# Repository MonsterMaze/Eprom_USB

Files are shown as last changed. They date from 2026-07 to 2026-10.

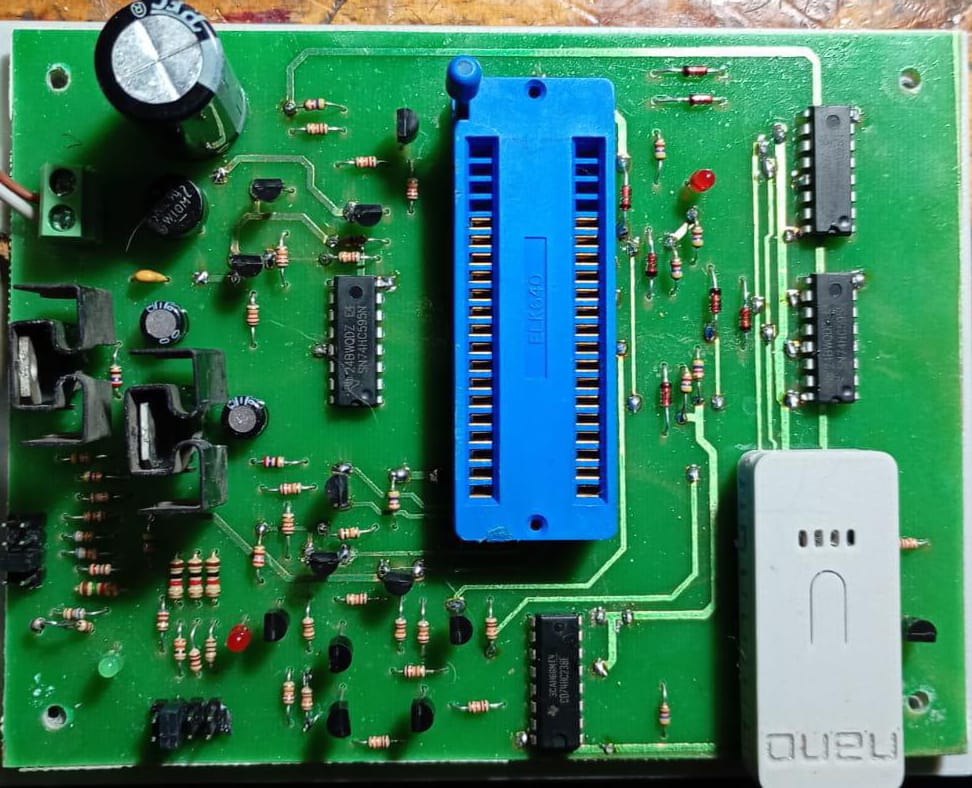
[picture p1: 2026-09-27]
images/new_pcb.jpg

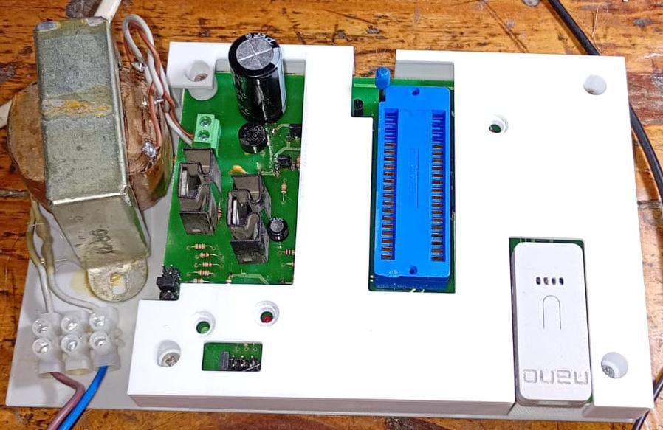
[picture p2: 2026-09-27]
images/new_pcb_3d_lid.jpg

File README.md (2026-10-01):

# Eprom_USB
2716 through 27080 Eprom Programmer
A programmer for UV EPROMs with capacities between 2Kb (2716 series) and 1Mb (27C080 series).  
It uses an Arduino NANO and few other components.  
As a starting point I used the excelent [EpromProgrammer_ciprian-stingu](https://github.com/ciprian-stingu/EpromProgrammer) project

## Why this project?
I need write eproms for pinball machines and I have two not working
- Parallel port (epromwillem) windows XP 32b
- Serial port (PGM27) for DOS.

So, I need a new Eprom programmer with a USB port.
That is why I started this project
my OS is Ubuntu 24.04 - 64b right now.

## Main features
* It supports a large number of EPROMs with different capacities  
* 2 programming speeds (normal & fast). Fast programming speed is available if you configure the VCC correctly  
* On fast programming alghoritm, writing a 27C040 EPROM takes around 290 seconds  
* Error detection on writing  
* Additional verify option  

## GUI Software (Ubuntu Linux_x64)
Actualized "CMakeLists.txt" and code with AI help for Ubuntu 24.04 OS.  
New version 1.12 with 0.35v of voltage margin. (0.25v)
The complete source for project is in [soft_linux](soft_linux)  
I have compiled for Ubuntu 24.04 and is included in Release v1.12 folder [Release 1.12/AppImage](https://github.com/MonsterMaze/Eprom_USB/releases/download/Linux/Eprom_USB-x86_64.AppImage)  
With some changes for icons, locale, debug etc.  
Last version Linux  [soft_linux v2.26](soft_linux)  

## GUI Software (windows_x64)
Actualized "CMakeLists.txt" for Windows 11 OS.  
QTCreator project compiler with some few changes.  
The complete source for project is in [soft_Win64](soft_Win64)  
I have compiled in w11 and is included in Release v1.12 folder [Release 1.12/Eprom_USB_v1.0_Windows_x64.zip](https://github.com/MonsterMaze/Eprom_USB/releases/download/v1.12/Eprom_USB_v1.0_Windows_x64.zip)

## GUI Software (windows_x64) v2
I have some problems with serial Port in windows (!)  
so...  
Modify all project and name v2
The complete source for project is in [soft_Win64_v2](soft_Win64_v2)  
I have compiled in w11 and is included in Release v1.20 folder [Release 1.20/Eprom_USB_v2_Windows_x64.zip](https://github.com/MonsterMaze/Eprom_USB/releases/download/v1.12/Eprom_USB_v1.0_Windows_x64.zip)  
I test the exe in w7-64b and w11-64b.

## Eprom_USB v1.0.0 - Multiplatform Release
This release contains the standalone, portable binaries for the Eprom USB Programmer software,   
fully compatible with both Windows and Linux. No external installation or build tools are required.

### 🪟 Windows Instructions (64-bit)
1. Download **`Eprom_USB_v1.0_Windows_x64.zip`**.  
2. Extract the `.zip` file entirely into a folder of your choice.  
3. Double-click **`Eprom_USB.exe`** to launch the graphical interface.  
*Note: All required Qt, Gettext (`libintl`), and `libiconv` DLLs are included inside the package.*

### 🐧 Linux / Ubuntu Instructions (64-bit AppImage)
1. Download **`Eprom_USB-x86_64.AppImage`**.  
2. Open your terminal, navigate to the folder where you downloaded the file, and grant it execution permissions:  
   ```bash
   chmod +x Eprom_USB-x86_64.AppImage
   ```
3. Launch the application by double-clicking it or running:
   ```bash
   ./Eprom_USB-x86_64.AppImage
   ```

⚠️ **Important for Linux Users (Serial Port Permission):**
If the application cannot open or detect your USB serial port, your Linux user might lack dialout permissions.  
Fix this by running the following command once, then log out and log back into Ubuntu:
```bash
sudo usermod -a -G dialout \$USER
```

---
*Developed with Qt 5 and CMake. Built with native MinGW (Windows) and GCC (Linux) compiler suites.*

## Arduino Software
The sketch for arduino nano is here: [arduino_nano](arduino_nano)

## Hardware
New schematics and PCB into FreeCAD project, was modify for me are in [FreeCAD](FreeCAD) folder.  
I add LM317 for the Vpp power (12.5v - 12.75 - 21v - 25v) from 24Vac input  
For non KiCad users, schematics and PCB [hardware](hardware) in PDF format  
New v2 PCB made by Ivana, in PDF format [hardware/PCB_v2](hardware/PCB_v2) front, bottom and silk

## Images
The screenshots and images of PCB and others are available in [images](images) folder

## Supported EPROMs

### 2716 — 2 KB

| Manufacturer | Part Number |
|---|---|
| Generic | 2716 |
| AMD | 2716 |
| Intel | 2716 |
| Hitachi | HN462716 |
| Mitsubishi | M5L2716K |
| Fujitsu | MBM2716 |
| Motorola | MCM2716 |
| NEC | µPD2716 |
| - | ET2716 |
| - | M2716 |

### 27C16 — 2 KB

| Manufacturer | Part Number |
|---|---|
| Generic | 27C16 |
| National Semi | 27C16 |
| AMD | AM2716B |
| National Semi | NMC27C16B |

### 2732 — 4 KB

| Manufacturer | Part Number |
|---|---|
| Generic | 2732 |
| AMD | AM2732 |
| AMD | AM9732 |
| Fairchild | F2732 |
| Hitachi | HN462732 |
| Intel | 2732A |
| ST | M2732A |
| Fujitsu | MBM2732 |
| NTE | NTE2732A |
| Toshiba | TMM2732D |
| NEC | µPD2732A |

### 27C32 — 4 KB

| Manufacturer | Part Number |
|---|---|
| Generic | 27C32 |
| AMD | AM2732B |
| National Semi | NMC27C32B |
| WSI | WS57C43C |

### 2764 — 8 KB

| Manufacturer | Part Number |
|---|---|
| Generic | 2764 |
| Intel | 2764A |
| ST | M2764A |
| Mitsubishi | M5L2764K |
| NTE | NTE2764 |
| Toshiba | TMM2764AD |

### 27C64 — 8 KB

| Manufacturer | Part Number |
|---|---|
| Generic | 27C64 |
| Microchip | 27C64 |
| Cypress | Cy7C266 |
| Fujitsu | MBM27C64 |
| National Semi | NMC27C64 |
| Texas Instruments| TMS27C64 |

### 27128 — 16 KB

| Manufacturer | Part Number |
|---|---|
| Generic | 27128 |
| Hitachi | HN4827128G |
| Hitachi | HN27128 |
| Intel | M27128A |
| ST | M27128A |
| Mitsubishi | M5L27128K |
| Mitsubishi | M5M27C128K |
| Fujitsu | MBM27128 |
| NTE | NTE21128 |
| Toshiba | TMM27128AD |
| Texas Instruments| TMS27128 |
| NEC | µPD27128 |

### 27C128 — 16 KB

| Manufacturer | Part Number |
|---|---|
| Generic | 27C128 |
| Microchip | 27C128 |
| AMD | AM27C128 |
| Atmel | AT27C128 |
| Cypress | CY27C128 |
| Sharp | LH57126 |
| ST | M27C128 |
| Oki | MSM27C128 |
| Fairchild | NM27C128 |
| National Semi | NM27C128 |
| - | QP27C128 |
| Texas Instruments| SMJ27C128 |
| Texas Instruments| TMS27C128 |

### 27256 — 32 KB

| Manufacturer | Part Number |
|---|---|
| Generic | 27256 |
| - | A68C256 |
| Atmel | AT27256 |
| Intel | 27256 |
| Mitsubishi | M5L27256K |
| Fujitsu | MBM27256 |
| Oki | MSM27256 |
| Toshiba | TMM27256 |
| NEC | µPD27256 |

### 27C256 — 32 KB

| Manufacturer | Part Number |
|---|---|
| Generic | 27C256 |
| Microchip | 27C256 |
| AMD | AM27C256 |
| AMD | AM27H256 |
| Sony | CXK27C256DQ |
| Cypress | CY27C256 |
| Cypress | CY27H256 |
| Cypress | CY7C274 |
| - | EM27C256 |
| - | FM27C256 |
| Hitachi | HN27C256A |
| Hitachi | HN27C256AG |
| ISSI | IS27C256 |
| ST | M27C256B |
| Mitsubishi | M5M27C256K |
| Fujitsu | MBM27C256 |
| - | 27HC256 |
| Oki | MSM27C256H |
| Fairchild | NM27C256 |
| National Semi | NM27C256 |
| National Semi | NM27LC256 |
| National Semi | NMC27C256 |
| National Semi | NMC87C257 |
| - | NPX27C256 |
| - | QP27C256 |
| SEEQ | 27C256 |
| SEEQ | M27C256 |
| ASI | SMJ27C256 |
| Texas Instruments| SMJ27C256 |
| - | SPM27C256 |
| Toshiba | TC57256 |
| Texas Instruments| TMS27C256 |
| Texas Instruments| TMS87C257 |
| NEC | µPD27C256 |

### 27512 — 64 KB

| Manufacturer | Part Number |
|---|---|
| Generic | 27512 |
| Intel | 27512 |
| AMD | AM27512 |
| Hitachi | HN27512 |
| ST | M27512 |
| Mitsubishi | M5L27512K |
| Oki | MSM27512 |
| Toshiba | TMM27512AD |

### 27C512 — 64 KB

| Manufacturer | Part Number |
|---|---|
| Generic | 27C512 |
| Microchip | 27C512 |
| Intel | 27C512 |
| Philips | 27C512 |
| AMD | AM27C512 |
| Sony | CXK27C512DQ |
| Cypress | CY27C512 |
| Cypress | CY27H512 |
| - | EM27C512 |
| - | FM27C512 |
| Hitachi | HN27C512 |
| ISSI | IS27HC512 |
| Fujitsu | MBM27C512 |
| Macronix | MX27C512 |
| National Semi | NM27C512 |
| National Semi | NM27P512 |
| ASI | SMJ27C512 |
| Texas Instruments| SMJ27C512 |
| Toshiba | TC57512AD |
| Texas Instruments| TMS27C512 |
| NEC | µPD27C512 |

### 27C010 — 128 KB

| Manufacturer | Part Number |
|---|---|
| Generic | 27C010 |
| AMD | AM27C010 |
| AMD | AM27H010 |
| AMD | AM27HB010 |
| Cypress | CY27C010 |
| Cypress | CY27H010 |
| Intel | 27C010 |
| - | EM27C010 |
| - | FM27C010 |
| Hitachi | HN27C101 |
| ISSI | IS27C010 |
| Mitsubishi | M5M27C101K |
| Fairchild | NM27C010 |
| National Semi | NM27C010 |
| National Semi | NMC27C010 |
| ASI | SMJ27C010 |
| Texas Instruments| SMJ27C010 |
| Texas Instruments| TMS27C010 |

### 27C1001 — 128 KB

| Manufacturer | Part Number |
|---|---|
| Generic | 27C1001 |
| Sony | CXK27C1001DQ |
| ST | M27C1001 |
| Fujitsu | MBM27C1001 |
| Oki | MSM27C1000 |
| Macronix | MX27C1000 |
| Toshiba | TC57C1001 |
| Toshiba | TC57H1001 |

### 27C020 — 256 KB

| Manufacturer | Part Number |
|---|---|
| Generic | 27C020 |
| AMD | AM27C020 |
| Cypress | CY27C020 |
| Intel | 27C020 |
| - | EM27C020 |
| ISSI | IS27C020 |
| National Semi | NM27C020 |
| Texas Instruments| TMS27C020 |

### 27C2001 — 256 KB

| Manufacturer | Part Number |
|---|---|
| Generic | 27C2001 |
| ST | M27C2001 |
| Oki | MSM27C2000 |
| NEC | µPD27C2001 |

### 27C040 — 512 KB

| Manufacturer | Part Number |
|---|---|
| Generic | 27C040 |
| AMD | AM27C040 |
| Cypress | CY27C040 |
| - | EM27C040 |
| - | FM27C040 |
| Intel | 27C040 |
| National Semi | NM27C040 |
| NXP | NXP27C040 |
| ASI | SMJ27C040 |
| Micross | SMJ27C040 |
| Texas Instruments| SMJ27C040 |
| Texas Instruments| TMS27C040 |

### 27C4001 — 512 KB

| Manufacturer | Part Number |
|---|---|
| Generic | 27C4001 |
| Hitachi | HN27C4001 |
| ST | M27C4001 |
| Fujitsu | MBM27C4001 |
| Oki | MSM27C401 |
| Macronix | MX27C4000 |
| Toshiba | TC57C4000 |
| NEC | µPD27C4001 |

### 27C080 — 1024 KB (1 MB)

| Manufacturer | Part Number |
|---|---|
| Generic | 27C080 |
| AMD | AM27C080 |
| Atmel | AT27LV080 |
| ST | M27C801 |
| Macronix | MX27C8000 |

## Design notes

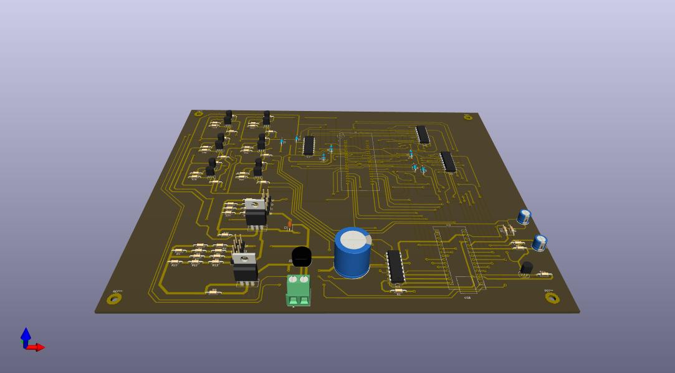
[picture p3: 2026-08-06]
images/Eprom_USB.jpg

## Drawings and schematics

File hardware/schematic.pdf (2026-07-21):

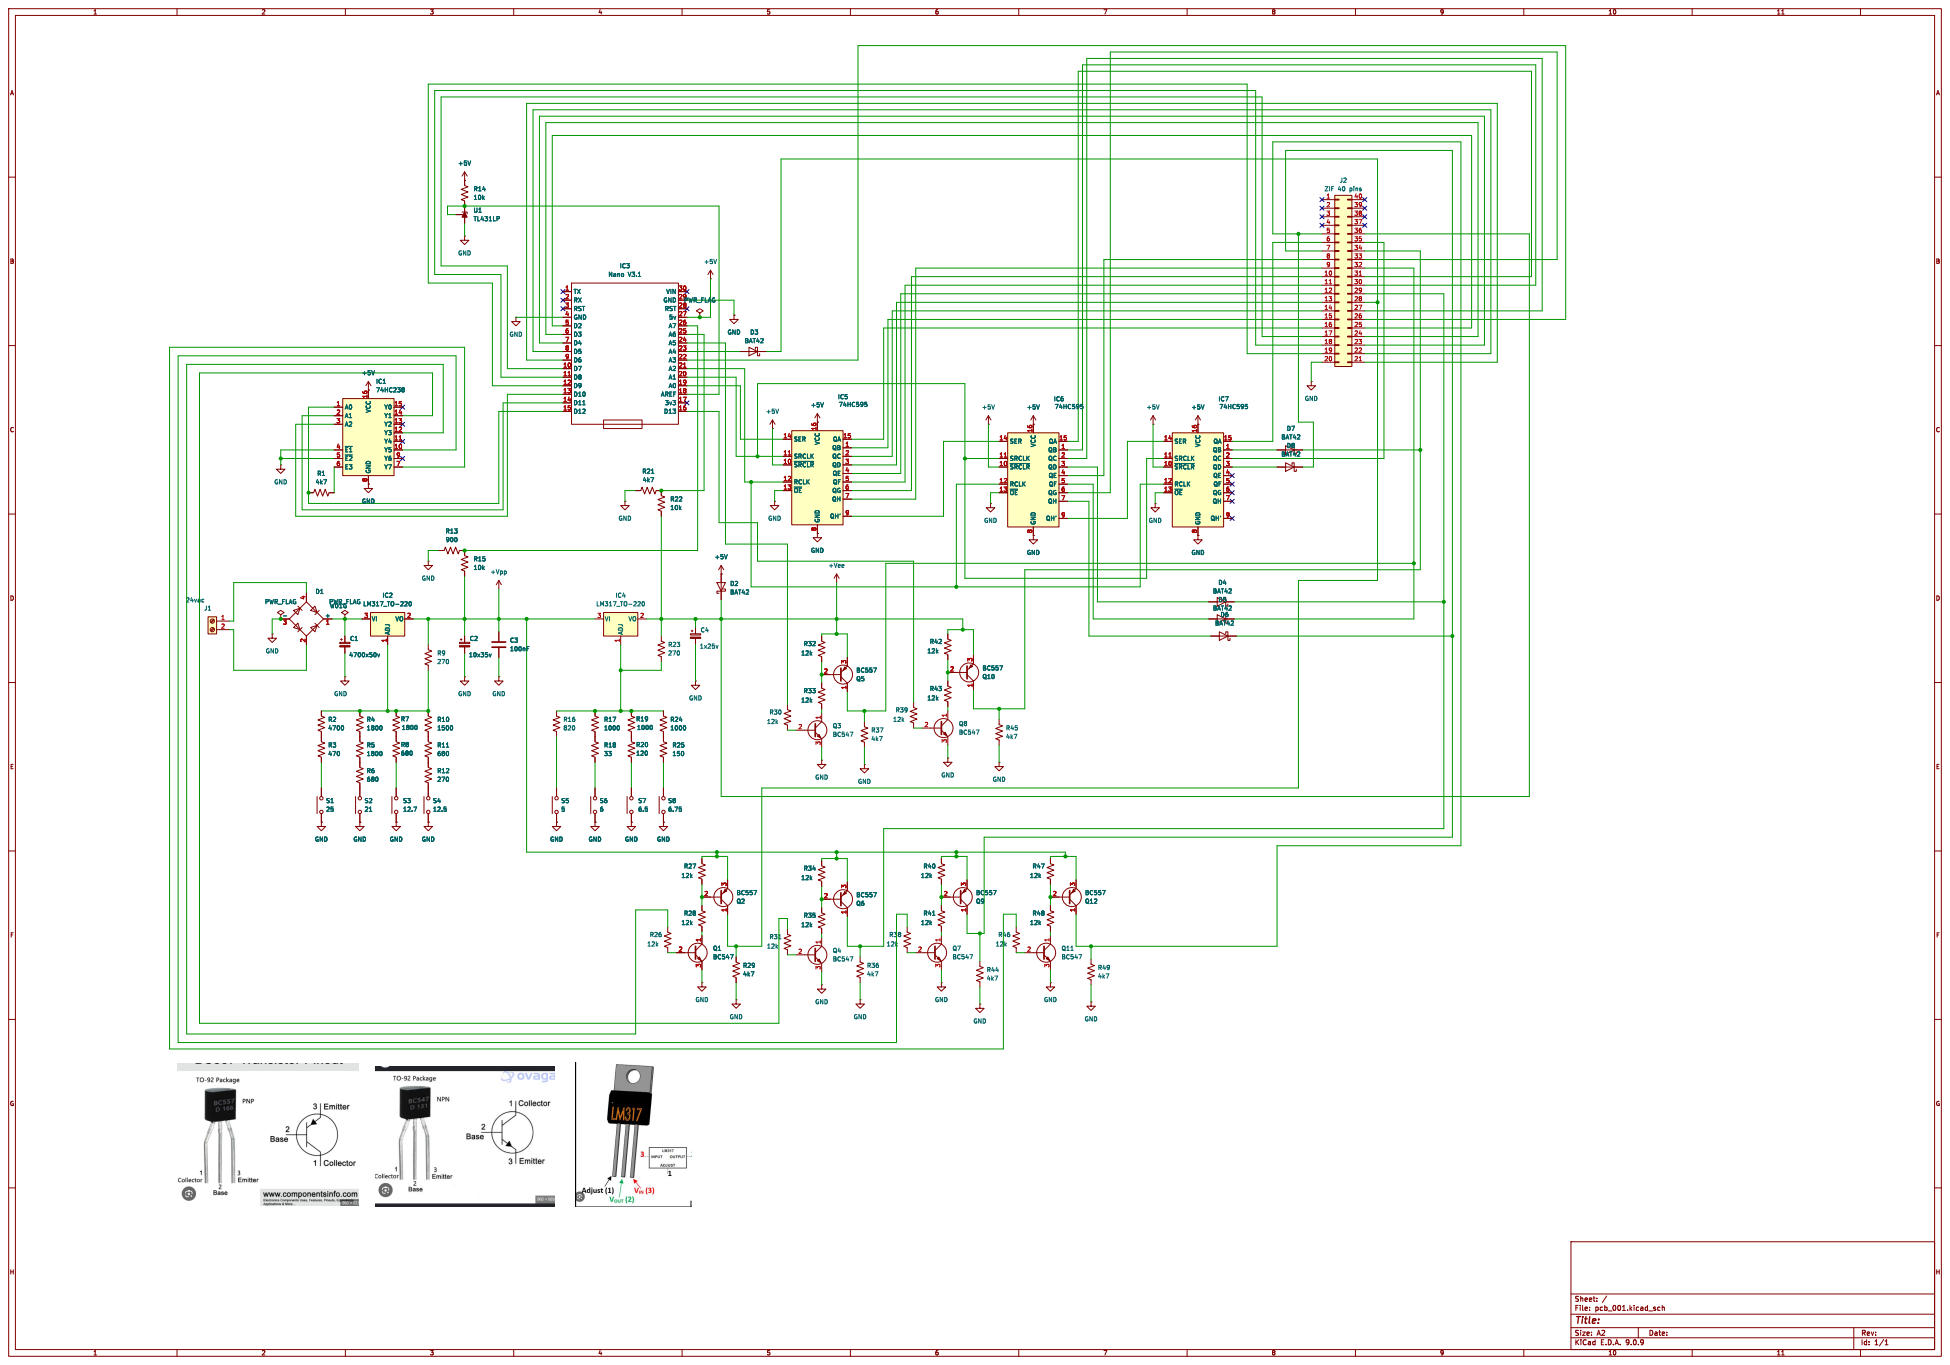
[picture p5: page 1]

8 QA 15 QB 1 QC 2 QD 3 QE 4 QF 5 QG 6 QH 7 QH' 9 +5V D8 BAT42 D7 BAT42 +5V

8 QA 15 QB 1 QC 2 QD 3 QE 4 QF 5 QG 6 QH 7 QH' 9 GND

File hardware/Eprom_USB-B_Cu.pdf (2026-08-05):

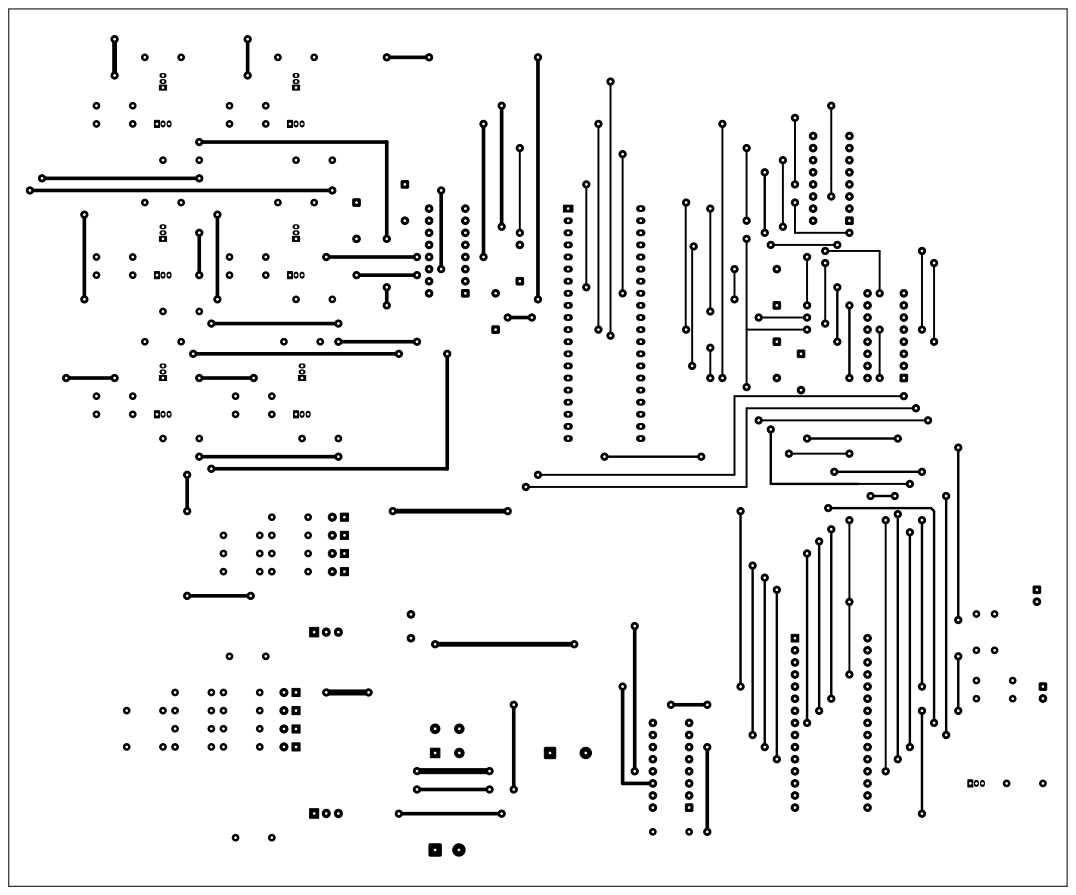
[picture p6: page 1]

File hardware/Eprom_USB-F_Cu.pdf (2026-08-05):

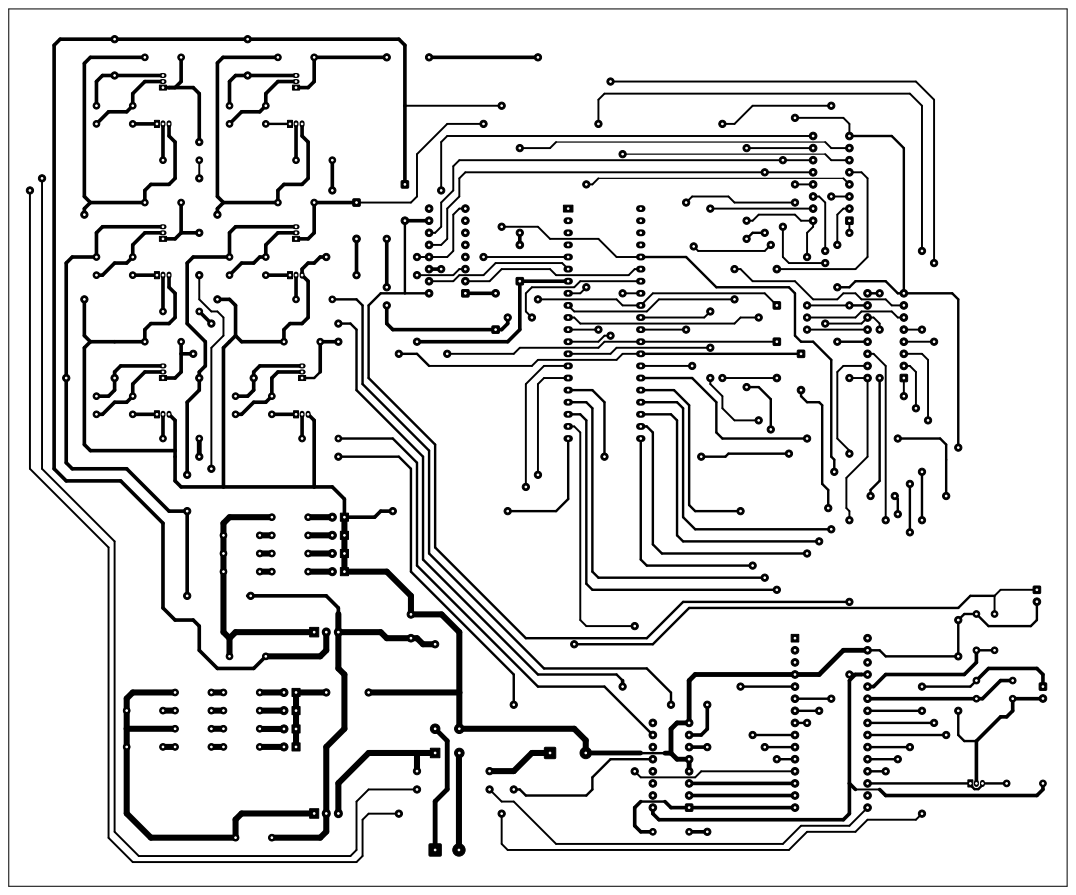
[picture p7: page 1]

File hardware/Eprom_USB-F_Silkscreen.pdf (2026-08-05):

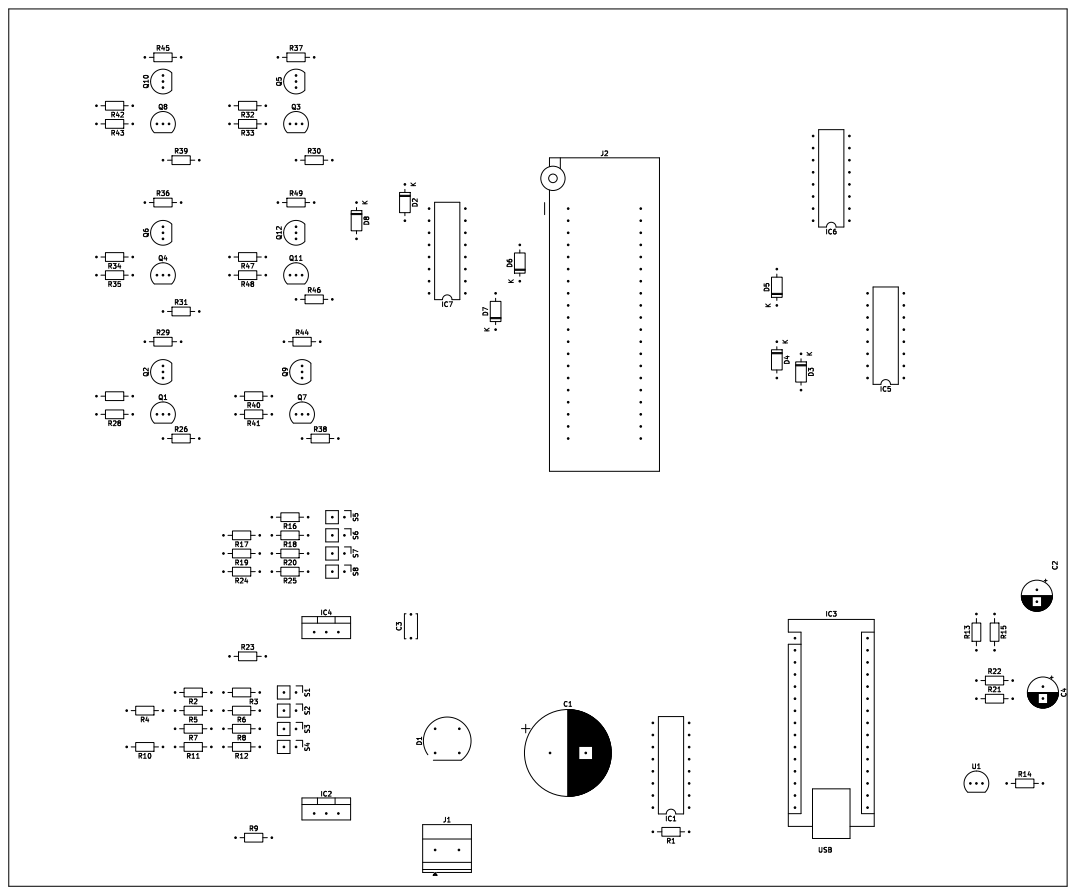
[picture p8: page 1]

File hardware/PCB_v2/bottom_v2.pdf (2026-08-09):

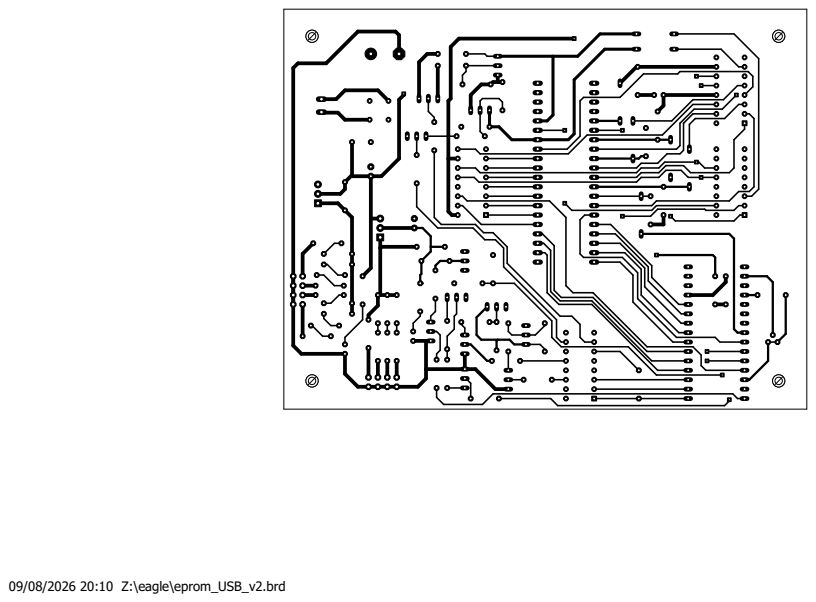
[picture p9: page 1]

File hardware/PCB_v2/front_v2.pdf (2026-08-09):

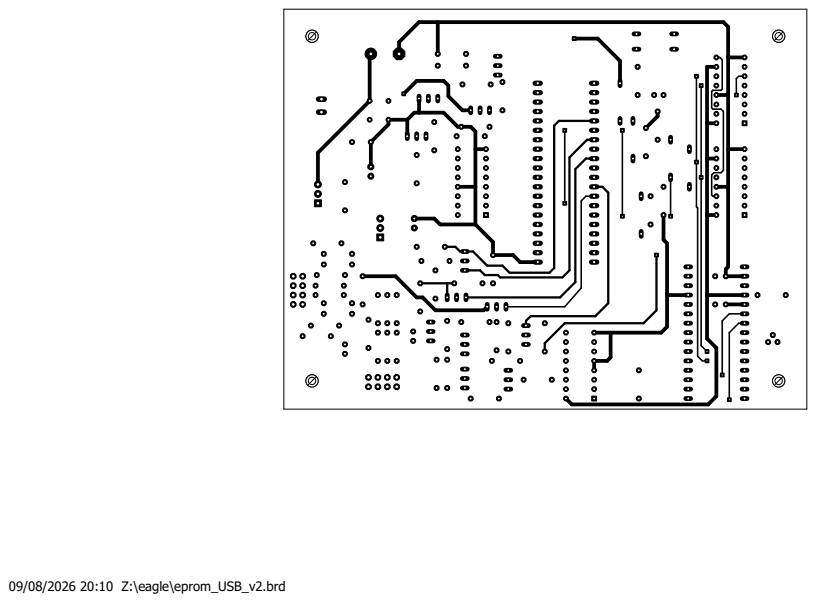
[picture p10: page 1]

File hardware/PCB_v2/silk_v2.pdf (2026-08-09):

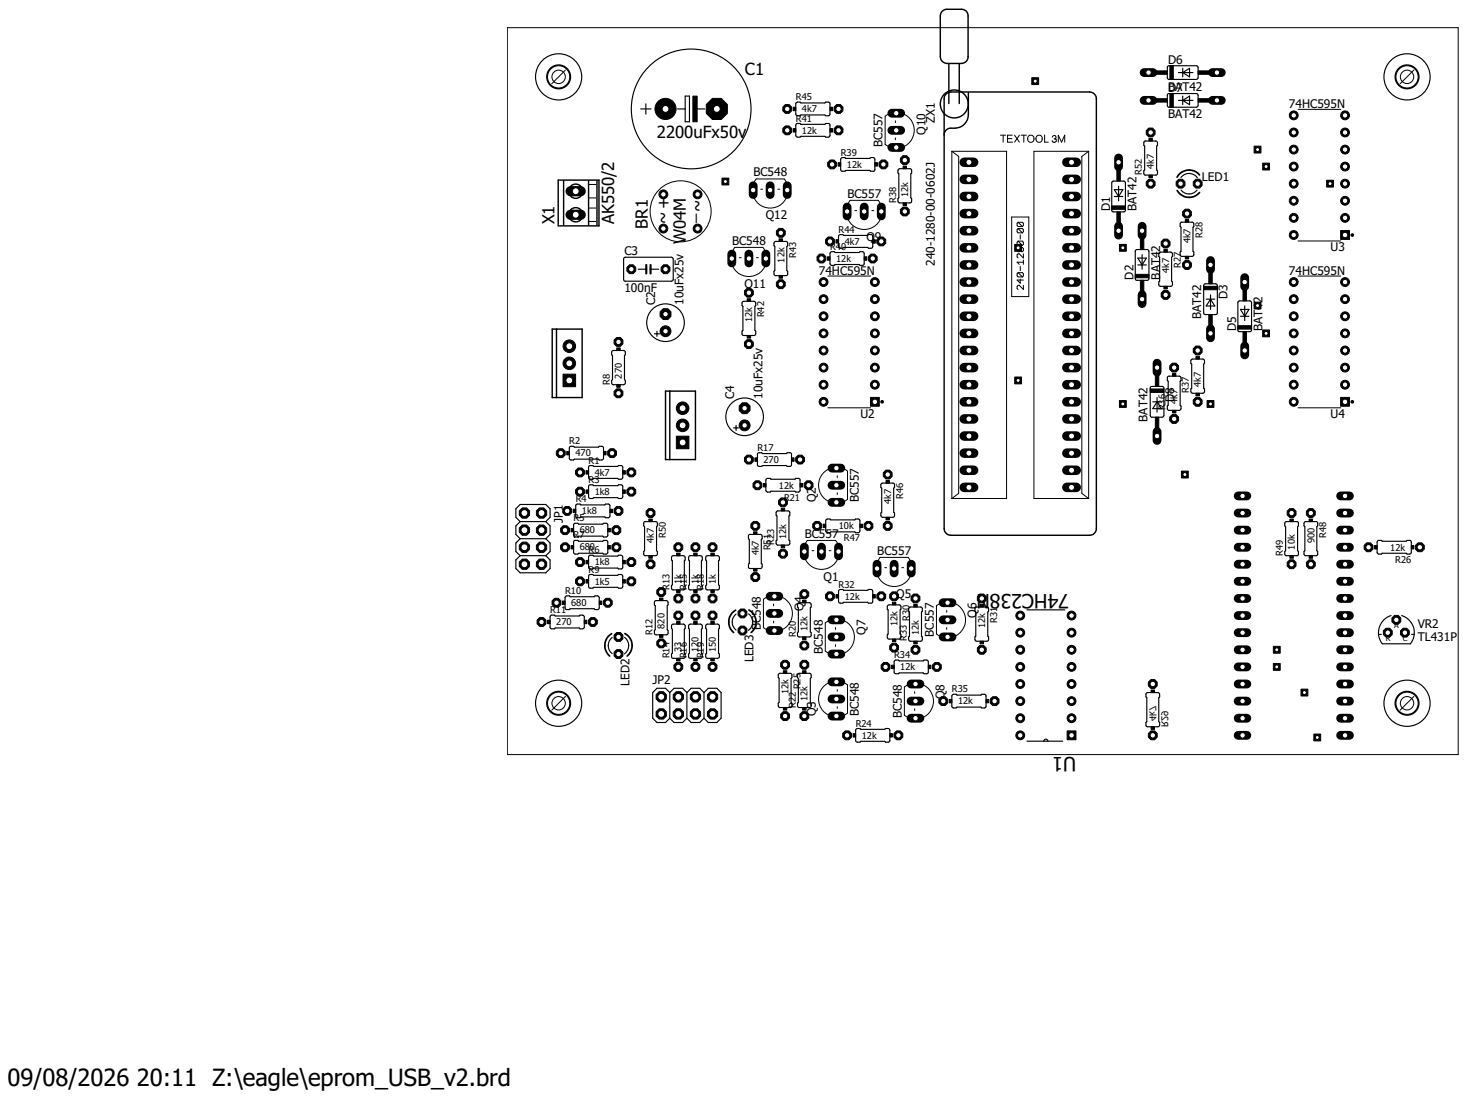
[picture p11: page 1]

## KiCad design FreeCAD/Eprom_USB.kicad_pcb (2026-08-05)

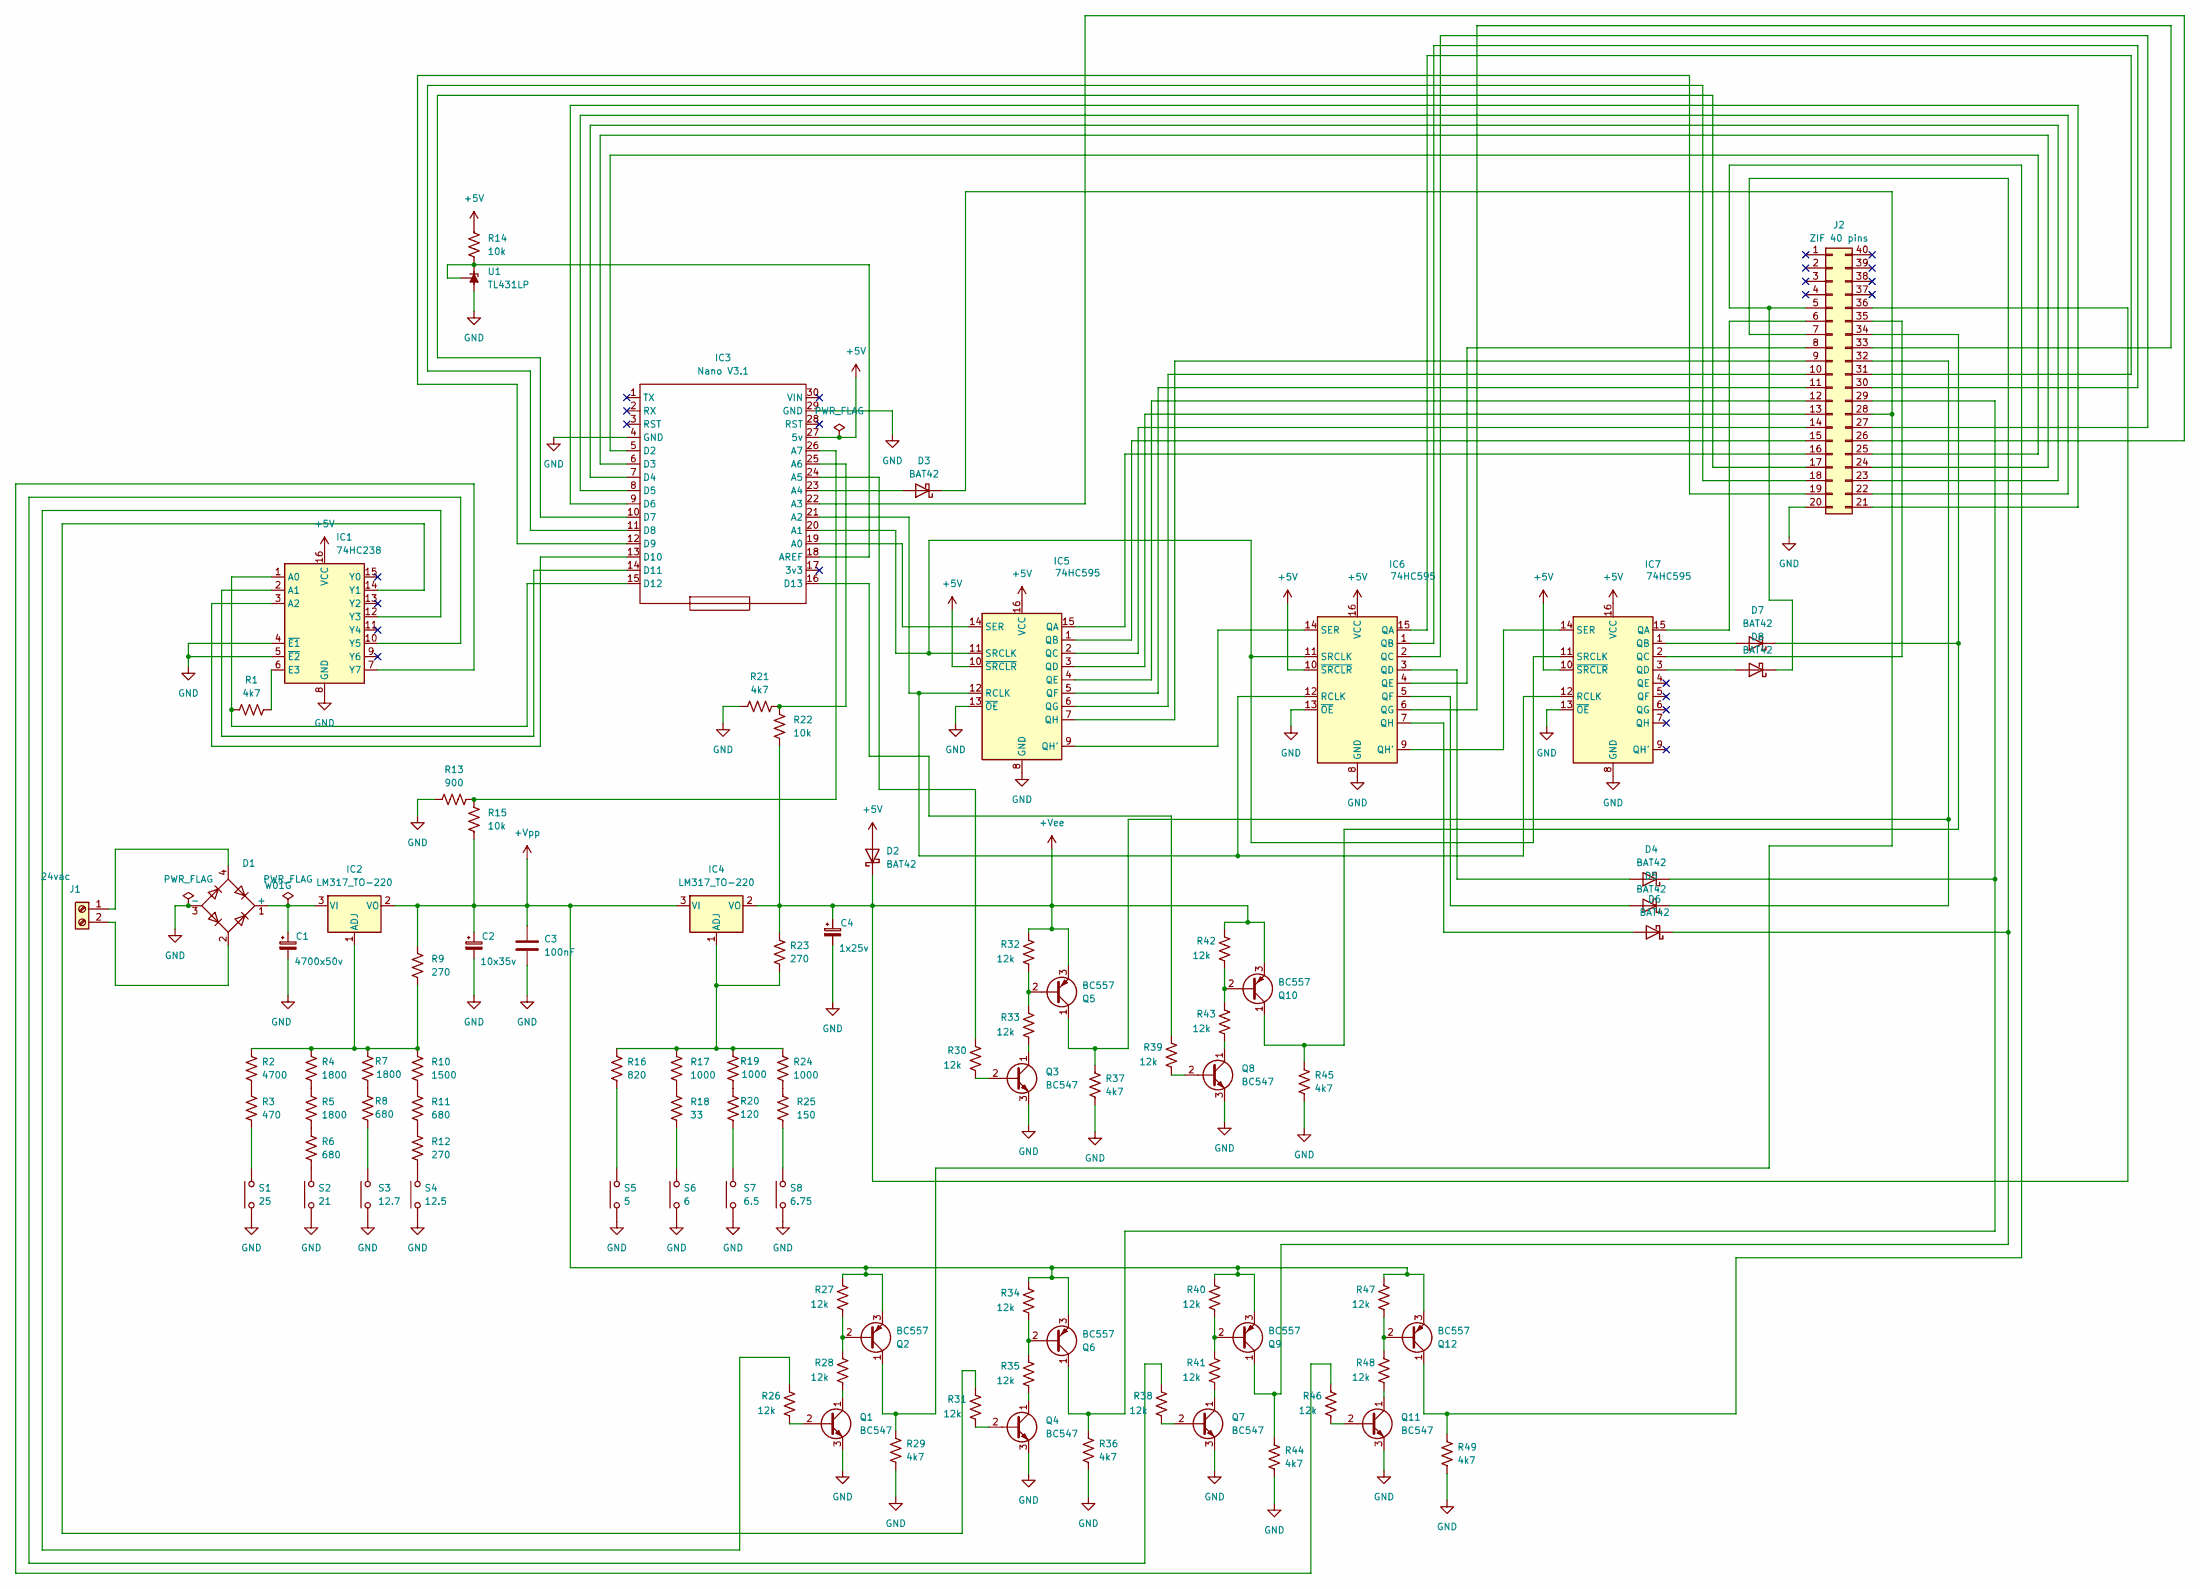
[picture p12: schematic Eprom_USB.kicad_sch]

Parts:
C1: 4700x50v; CP_Radial_D18.0mm_P7.50mm
C2: 10x35v; CP_Radial_D6.3mm_P2.50mm
C3: 100nF; C_Disc_D5.0mm_W2.5mm_P5.00mm
C4: 1x25v; CP_Radial_D6.3mm_P2.50mm
D1: W01G; Diode_Bridge_Round_D9.8mm
D2, D3, D4, D5, D6, D7, D8: BAT42; D_DO-35_SOD27_P7.62mm_Horizontal
IC1: 74HC238; DIP-16_W7.62mm
IC2, IC4: LM317_TO-220; TO-220-3_Vertical
IC3: Nano V3.1; Arduino_Nano
IC5, IC6, IC7: 74HC595; DIP-16_W7.62mm
J1: 24vac; TerminalBlock_Phoenix_MKDS-1,5-2_1x02_P5.00mm_Horizontal
J2: ZIF 40 pins; DIP_Socket-40_W11.9mm_W12.7mm_W15.24mm_W17.78mm_W18.5mm_3M_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
Q1, Q3, Q4, Q7, Q8, Q11: BC547; TO-92_Inline
Q2, Q5, Q6, Q9, Q10, Q12: BC557; TO-92_Inline
R1, R21, R29, R36, R37, R44, R45, R49: 4k7; R_Axial_DIN0204_L3.6mm_D1.6mm_P7.62mm_Horizontal
R2: 4700; R_Axial_DIN0204_L3.6mm_D1.6mm_P7.62mm_Horizontal
R3: 470; R_Axial_DIN0204_L3.6mm_D1.6mm_P7.62mm_Horizontal
R4, R5, R7: 1800; R_Axial_DIN0204_L3.6mm_D1.6mm_P7.62mm_Horizontal
R6, R8, R11: 680; R_Axial_DIN0204_L3.6mm_D1.6mm_P7.62mm_Horizontal
R9, R12, R23: 270; R_Axial_DIN0204_L3.6mm_D1.6mm_P7.62mm_Horizontal
R10: 1500; R_Axial_DIN0204_L3.6mm_D1.6mm_P7.62mm_Horizontal
R13: 900; R_Axial_DIN0204_L3.6mm_D1.6mm_P7.62mm_Horizontal
R14, R15, R22: 10k; R_Axial_DIN0204_L3.6mm_D1.6mm_P7.62mm_Horizontal
R16: 820; R_Axial_DIN0204_L3.6mm_D1.6mm_P7.62mm_Horizontal
R17, R19, R24: 1000; R_Axial_DIN0204_L3.6mm_D1.6mm_P7.62mm_Horizontal
R18: 33; R_Axial_DIN0204_L3.6mm_D1.6mm_P7.62mm_Horizontal
R20: 120; R_Axial_DIN0204_L3.6mm_D1.6mm_P7.62mm_Horizontal
R25: 150; R_Axial_DIN0204_L3.6mm_D1.6mm_P7.62mm_Horizontal
R26, R27, R28, R30, R31, R32, R33, R34, R35, R38, R39, R40, R41, R42, R43, R46, R47, R48: 12k; R_Axial_DIN0204_L3.6mm_D1.6mm_P7.62mm_Horizontal
S1: 25; PinHeader_1x02_P2.54mm_Vertical
S2: 21; PinHeader_1x02_P2.54mm_Vertical
S3: 12.7; PinHeader_1x02_P2.54mm_Vertical
S4: 12.5; PinHeader_1x02_P2.54mm_Vertical
S5: 5; PinHeader_1x02_P2.54mm_Vertical
S6: 6; PinHeader_1x02_P2.54mm_Vertical
S7: 6.5; PinHeader_1x02_P2.54mm_Vertical
S8: 6.75; PinHeader_1x02_P2.54mm_Vertical
U1: TL431LP; TO-92_Inline

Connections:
+5V: D2.2 (A), IC1.16 (VCC), IC3.27 (5v), IC5.10 (~SRCLR), IC5.16 (VCC), IC6.10 (~SRCLR), IC6.16 (VCC), IC7.10 (~SRCLR), IC7.16 (VCC), R14.2
+Vee: C4.1, D2.1 (K), IC4.2 (VO), J2.36, Q5.3 (E), Q10.3 (E), R22.1, R23.2, R32.2, R42.2
+Vpp: C2.1, C3.1, IC2.2 (VO), IC4.3 (VI), Q2.3 (E), Q6.3 (E), Q9.3 (E), Q12.3 (E), R9.2, R15.1, R27.2, R34.2, R40.2, R47.2
GND: C1.2, C2.2, C3.2, C4.2, D1.3 (-), IC1.4 (~E1), IC1.5 (~E2), IC1.8 (GND), IC3.4 (GND), IC3.29 (GND), IC5.8 (GND), IC5.13 (~OE), IC6.8 (GND), IC6.13 (~OE), IC7.8 (GND), IC7.13 (~OE), J2.20, Q1.3 (E), Q3.3 (E), Q4.3 (E), Q7.3 (E), Q8.3 (E), Q11.3 (E), R13.2, R21.2, R29.1, R36.1, R37.1, R44.1, R45.1, R49.1, S1.1, S2.1, S3.1, S4.1, S5.1, S6.1, S7.1, S8.1, U1.2 (A)
unnamed: C1.1, D1.1 (+), IC2.3 (VI)
unnamed: D3.2 (A), IC3.23 (A4)
unnamed: D3.1 (K), J2.28, Q2.1 (C), R29.2
unnamed: D4.2 (A), IC6.3 (QD)
unnamed: D4.1 (K), J2.29, Q6.1 (C), R36.2
unnamed: D5.2 (A), IC6.5 (QF)
unnamed: D5.1 (K), J2.32, Q5.1 (C), R37.2
unnamed: D6.2 (A), IC6.7 (QH)
unnamed: D6.1 (K), J2.7, Q9.1 (C), R44.2
unnamed: D7.2 (A), IC7.1 (QB)
unnamed: D7.1 (K), J2.34, Q10.1 (C), R45.2
unnamed: D8.2 (A), IC7.3 (QD)
unnamed: D8.1 (K), J2.5, Q12.1 (C), R49.2
unnamed: IC1.1 (A0), IC3.15 (D12), R1.2
unnamed: IC1.2 (A1), IC3.14 (D11)
unnamed: IC1.3 (A2), IC3.13 (D10)
unnamed: IC1.6 (E3), R1.1
unnamed: IC1.14 (Y1), R31.2
unnamed: IC1.12 (Y3), R26.2
unnamed: IC1.10 (Y5), R38.2
unnamed: IC1.7 (Y7), R46.2
unnamed: IC2.1 (ADJ), R2.2, R4.2, R7.2, R9.1, R10.2
unnamed: IC3.19 (A0), IC5.14 (SER)
unnamed: IC3.20 (A1), IC5.11 (SRCLK), IC6.11 (SRCLK), IC7.11 (SRCLK)
unnamed: IC3.21 (A2), IC5.12 (RCLK), IC6.12 (RCLK), IC7.12 (RCLK)
unnamed: IC3.22 (A3), J2.26
unnamed: IC3.24 (A5), R30.2
unnamed: IC3.25 (A6), R21.1, R22.2
unnamed: IC3.26 (A7), R13.1, R15.2
unnamed: IC3.18 (AREF), R14.1, U1.1 (REF), U1.3 (K)
unnamed: IC3.5 (D2), J2.25
unnamed: IC3.6 (D3), J2.24
unnamed: IC3.7 (D4), J2.23
unnamed: IC3.8 (D5), J2.22
unnamed: IC3.9 (D6), J2.21
unnamed: IC3.10 (D7), J2.17
unnamed: IC3.11 (D8), J2.18
unnamed: IC3.12 (D9), J2.19
unnamed: IC3.16 (D13), R39.2
unnamed: IC4.1 (ADJ), R16.2, R17.2, R19.2, R23.1, R24.2
unnamed: IC5.15 (QA), J2.16
unnamed: IC5.1 (QB), J2.15
unnamed: IC5.2 (QC), J2.14
unnamed: IC5.3 (QD), J2.13
unnamed: IC5.4 (QE), J2.12
unnamed: IC5.5 (QF), J2.11
unnamed: IC5.6 (QG), J2.10
unnamed: IC5.9 (QH'), IC6.14 (SER)
unnamed: IC5.7 (QH), J2.9
unnamed: IC6.15 (QA), J2.31
unnamed: IC6.1 (QB), J2.30
unnamed: IC6.2 (QC), J2.27
unnamed: IC6.4 (QE), J2.8
unnamed: IC6.6 (QG), J2.33
unnamed: IC6.9 (QH'), IC7.14 (SER)
unnamed: IC7.15 (QA), J2.6
unnamed: IC7.2 (QC), J2.35
unnamed: D1.4, J1.1
unnamed: D1.2, J1.2
unnamed: Q1.2 (B), R26.1
unnamed: Q1.1 (C), R28.1
unnamed: Q2.2 (B), R27.1, R28.2
unnamed: Q3.2 (B), R30.1
unnamed: Q3.1 (C), R33.1
unnamed: Q4.2 (B), R31.1
unnamed: Q4.1 (C), R35.1
unnamed: Q5.2 (B), R32.1, R33.2
unnamed: Q6.2 (B), R34.1, R35.2
unnamed: Q7.2 (B), R38.1
unnamed: Q7.1 (C), R41.1
unnamed: Q8.2 (B), R39.1
unnamed: Q8.1 (C), R43.1
unnamed: Q9.2 (B), R40.1, R41.2
unnamed: Q10.2 (B), R42.1, R43.2
unnamed: Q11.2 (B), R46.1
unnamed: Q11.1 (C), R48.1
unnamed: Q12.2 (B), R47.1, R48.2
unnamed: R2.1, R3.2
unnamed: R3.1, S1.2
unnamed: R4.1, R5.2
unnamed: R5.1, R6.2
unnamed: R6.1, S2.2
unnamed: R7.1, R8.2
unnamed: R8.1, S3.2
unnamed: R10.1, R11.2
unnamed: R11.1, R12.2
unnamed: R12.1, S4.2
unnamed: R16.1, S5.2
unnamed: R17.1, R18.2
unnamed: R18.1, S6.2
unnamed: R19.1, R20.2
unnamed: R20.1, S7.2
unnamed: R24.1, R25.2
unnamed: R25.1, S8.2

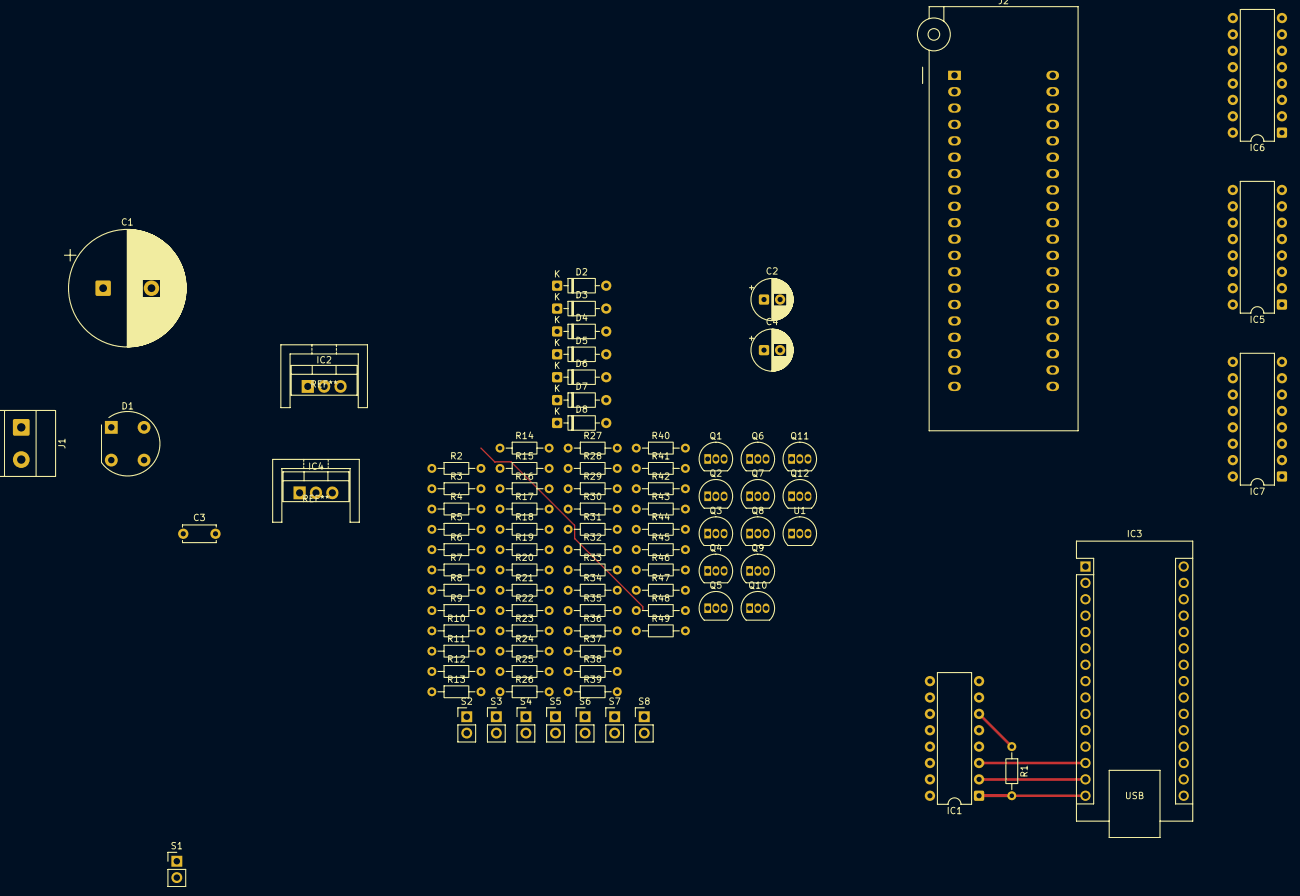
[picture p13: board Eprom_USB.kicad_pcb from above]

Board: 2 copper layers, 91 parts (0 on the bottom side), 98 nets.

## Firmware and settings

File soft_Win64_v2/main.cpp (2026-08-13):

/**
 * 
 * Eprom Programmer
 * 
 * Copyright (C) 2021-2023 Ciprian Stingu
 * ciprian stingu at gmail dot com
 * 
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
 */
//------------------------------------------------------------------------------
#include "src/QtGui.h"
#include <stdlib.h>

#ifdef __linux__
#include <sys/resource.h>
#endif

int main(int argc, char **argv)
{
#ifdef __linux__
    struct rlimit core_limits;
    core_limits.rlim_cur = core_limits.rlim_max = RLIM_INFINITY;
    setrlimit(RLIMIT_CORE, &core_limits);
#endif

    QtGui *gui = new QtGui(argc, argv);
    gui->Run();

    delete gui;
    return 0;
}
//------------------------------------------------------------------------------

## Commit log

2026-08-05 Renombrar carpeta de gui a software
2026-08-05 freecad move
    [Eprom_USB.kicad_pcb, Eprom_USB.kicad_sch, case.FCStd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]

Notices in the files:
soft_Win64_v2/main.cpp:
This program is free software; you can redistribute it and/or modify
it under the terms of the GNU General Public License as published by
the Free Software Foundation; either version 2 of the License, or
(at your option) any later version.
